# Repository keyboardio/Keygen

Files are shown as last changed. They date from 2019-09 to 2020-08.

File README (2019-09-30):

Setting up:

* Install perl modules
* Check out git submodule

Perl Dependencies:

JSON::XS
Moose

Non-perl Dependencies:

This tool currently builds KiCad 6.0 projects. That's not strictly necessary. If you need us to back down to 5.1, please say so.

There's a git submodule of 'kicad', which includes the keyboardio kicad footprints. Pull requests over there are welcome.

Usage:

perl layout.pl --usb=c --project=104-key --layout=kle-layouts/104.json 
cd 104-key
kicad 104-key.pro

Notes:

It currently generates schematics and layouts assuming a ATMega32U4. The schematic has sheets for three different ways to wire things up: components-on-pcb, teensy 2.0++, arduino-micro.
I know the pro micro is more popular in Japan and I'm happy to have that added as an option.
It'd just need another schematic sheet in the template project and a footprint for adding it to the pcb.
led support is a boolean option. Right now, LEDs are designed as dumb rgb pixels + an issi controller.
the logic parts of the PCB don't get placed or connected to the switch and led matrix automatically. That's a much harder wiring problem.
Instead, I hand-drew layouts for those and place them off the side of the PCB for you to drag into place and wire up.
I have produced two PCBs based on earlier versions of this tool with some manual rework. They did -work-. But results are not guaranteed.

-Jesse
jesse@keyboard.io

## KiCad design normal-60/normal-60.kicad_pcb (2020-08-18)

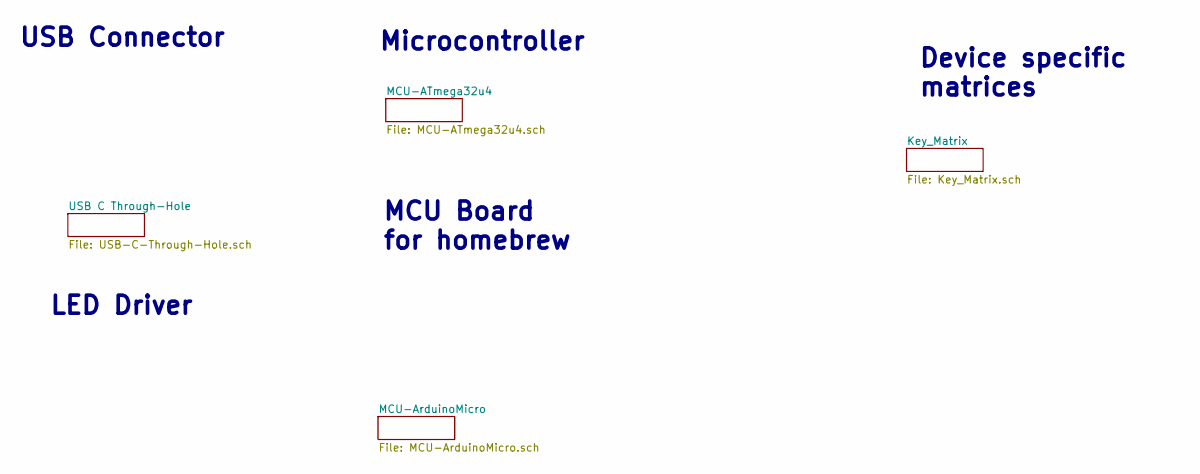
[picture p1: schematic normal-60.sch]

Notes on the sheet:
Device specific matrices
USB Connector
LED Driver
Microcontroller
MCU Board for homebrew

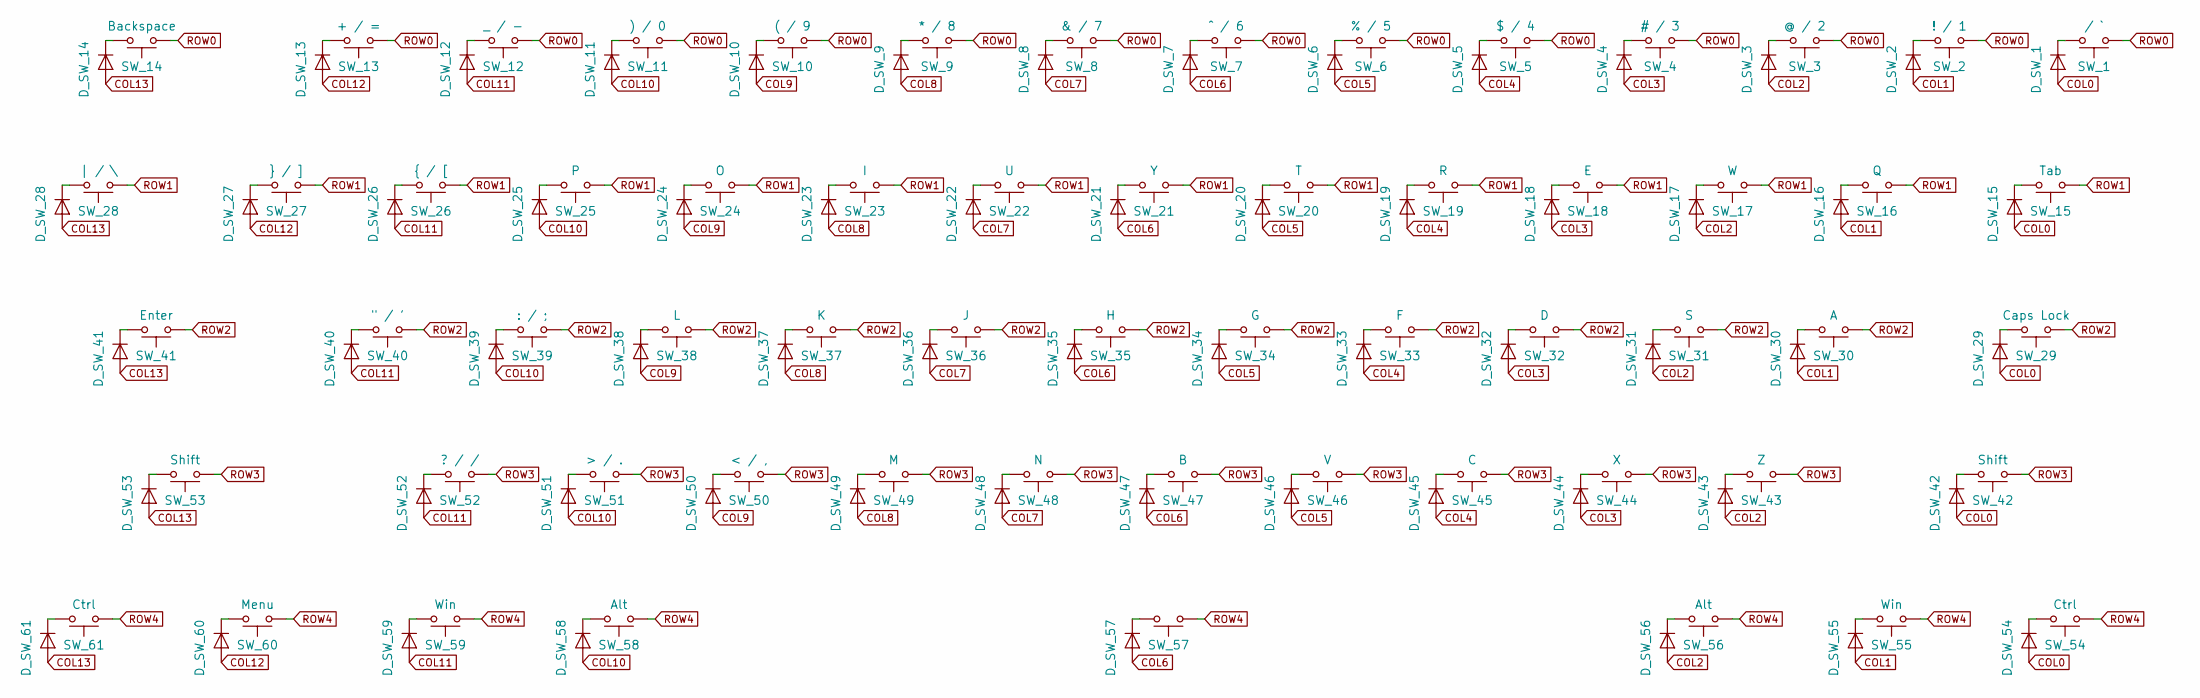
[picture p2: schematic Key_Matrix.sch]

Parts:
D_SW_1, D_SW_2, D_SW_3, D_SW_4, D_SW_5, D_SW_6, D_SW_7, D_SW_8, D_SW_9, D_SW_10, D_SW_11, D_SW_12, D_SW_13, D_SW_14, D_SW_15, D_SW_16, D_SW_17, D_SW_18, D_SW_19, D_SW_20, D_SW_21, D_SW_22, D_SW_23, D_SW_24, D_SW_25, D_SW_26, D_SW_27, D_SW_28, D_SW_29, D_SW_30, D_SW_31, D_SW_32, D_SW_33, D_SW_34, D_SW_35, D_SW_36, D_SW_37, D_SW_38, D_SW_39, D_SW_40, D_SW_41, D_SW_42, D_SW_43, D_SW_44, D_SW_45, D_SW_46, D_SW_47, D_SW_48, D_SW_49, D_SW_50, D_SW_51, D_SW_52, D_SW_53, D_SW_54, D_SW_55, D_SW_56, D_SW_57, D_SW_58, D_SW_59, D_SW_60, D_SW_61: 1N4148; D_SOD-123
SW_1: ~ / `; MX-KailhClip-1.00u
SW_2: ! / 1; MX-KailhClip-1.00u
SW_3: @ / 2; MX-KailhClip-1.00u
SW_4: # / 3; MX-KailhClip-1.00u
SW_5: $ / 4; MX-KailhClip-1.00u
SW_6: % / 5; MX-KailhClip-1.00u
SW_7: ^ / 6; MX-KailhClip-1.00u
SW_8: & / 7; MX-KailhClip-1.00u
SW_9: * / 8; MX-KailhClip-1.00u
SW_10: ( / 9; MX-KailhClip-1.00u
SW_11: ) / 0; MX-KailhClip-1.00u
SW_12: _ / -; MX-KailhClip-1.00u
SW_13: + / =; MX-KailhClip-1.00u
SW_14: Backspace; MX-KailhClip-1.00u
SW_15: Tab; MX-KailhClip-1.00u
SW_16: Q; MX-KailhClip-1.00u
SW_17: W; MX-KailhClip-1.00u
SW_18: E; MX-KailhClip-1.00u
SW_19: R; MX-KailhClip-1.00u
SW_20: T; MX-KailhClip-1.00u
SW_21: Y; MX-KailhClip-1.00u
SW_22: U; MX-KailhClip-1.00u
SW_23: I; MX-KailhClip-1.00u
SW_24: O; MX-KailhClip-1.00u
SW_25: P; MX-KailhClip-1.00u
SW_26: { / [; MX-KailhClip-1.00u
SW_27: } / ]; MX-KailhClip-1.00u
SW_28: | / \\; MX-KailhClip-1.00u
SW_29: Caps Lock; MX-KailhClip-1.00u
SW_30: A; MX-KailhClip-1.00u
SW_31: S; MX-KailhClip-1.00u
SW_32: D; MX-KailhClip-1.00u
SW_33: F; MX-KailhClip-1.00u
SW_34: G; MX-KailhClip-1.00u
SW_35: H; MX-KailhClip-1.00u
SW_36: J; MX-KailhClip-1.00u
SW_37: K; MX-KailhClip-1.00u
SW_38: L; MX-KailhClip-1.00u
SW_39: : / ;; MX-KailhClip-1.00u
SW_40: \" / '; MX-KailhClip-1.00u
SW_41: Enter; MX-KailhClip-1.00u
SW_42, SW_53: Shift; MX-KailhClip-1.00u
SW_43: Z; MX-KailhClip-1.00u
SW_44: X; MX-KailhClip-1.00u
SW_45: C; MX-KailhClip-1.00u
SW_46: V; MX-KailhClip-1.00u
SW_47: B; MX-KailhClip-1.00u
SW_48: N; MX-KailhClip-1.00u
SW_49: M; MX-KailhClip-1.00u
SW_50: < / ,; MX-KailhClip-1.00u
SW_51: > / .; MX-KailhClip-1.00u
SW_52: ? / /; MX-KailhClip-1.00u
SW_54, SW_61: Ctrl; MX-KailhClip-1.00u
SW_55, SW_59: Win; MX-KailhClip-1.00u
SW_56, SW_58: Alt; MX-KailhClip-1.00u
SW_57: MX-KailhClip-1.00u
SW_60: Menu; MX-KailhClip-1.00u

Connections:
COL0: D_SW_1.2 (A), D_SW_15.2 (A), D_SW_29.2 (A), D_SW_42.2 (A), D_SW_54.2 (A); also elsewhere on the board
COL1: D_SW_2.2 (A), D_SW_16.2 (A), D_SW_30.2 (A), D_SW_55.2 (A); also elsewhere on the board
COL2: D_SW_3.2 (A), D_SW_17.2 (A), D_SW_31.2 (A), D_SW_43.2 (A), D_SW_56.2 (A); also elsewhere on the board
COL3: D_SW_4.2 (A), D_SW_18.2 (A), D_SW_32.2 (A), D_SW_44.2 (A); also elsewhere on the board
COL4: D_SW_5.2 (A), D_SW_19.2 (A), D_SW_33.2 (A), D_SW_45.2 (A); also elsewhere on the board
COL5: D_SW_6.2 (A), D_SW_20.2 (A), D_SW_34.2 (A), D_SW_46.2 (A); also elsewhere on the board
COL6: D_SW_7.2 (A), D_SW_21.2 (A), D_SW_35.2 (A), D_SW_47.2 (A), D_SW_57.2 (A); also elsewhere on the board
COL7: D_SW_8.2 (A), D_SW_22.2 (A), D_SW_36.2 (A), D_SW_48.2 (A); also elsewhere on the board
COL8: D_SW_9.2 (A), D_SW_23.2 (A), D_SW_37.2 (A), D_SW_49.2 (A); also elsewhere on the board
COL9: D_SW_10.2 (A), D_SW_24.2 (A), D_SW_38.2 (A), D_SW_50.2 (A); also elsewhere on the board
COL10: D_SW_11.2 (A), D_SW_25.2 (A), D_SW_39.2 (A), D_SW_51.2 (A), D_SW_58.2 (A); also elsewhere on the board
COL11: D_SW_12.2 (A), D_SW_26.2 (A), D_SW_40.2 (A), D_SW_52.2 (A), D_SW_59.2 (A); also elsewhere on the board
COL12: D_SW_13.2 (A), D_SW_27.2 (A), D_SW_60.2 (A); also elsewhere on the board
COL13: D_SW_14.2 (A), D_SW_28.2 (A), D_SW_41.2 (A), D_SW_53.2 (A), D_SW_61.2 (A); also elsewhere on the board
unnamed: D_SW_1.1 (K), SW_1.2
unnamed: D_SW_2.1 (K), SW_2.2
unnamed: D_SW_3.1 (K), SW_3.2
unnamed: D_SW_4.1 (K), SW_4.2
unnamed: D_SW_5.1 (K), SW_5.2
unnamed: D_SW_6.1 (K), SW_6.2
unnamed: D_SW_7.1 (K), SW_7.2
unnamed: D_SW_8.1 (K), SW_8.2
unnamed: D_SW_9.1 (K), SW_9.2
unnamed: D_SW_10.1 (K), SW_10.2
unnamed: D_SW_11.1 (K), SW_11.2
unnamed: D_SW_12.1 (K), SW_12.2
unnamed: D_SW_13.1 (K), SW_13.2
unnamed: D_SW_14.1 (K), SW_14.2
unnamed: D_SW_15.1 (K), SW_15.2
unnamed: D_SW_16.1 (K), SW_16.2
unnamed: D_SW_17.1 (K), SW_17.2
unnamed: D_SW_18.1 (K), SW_18.2
unnamed: D_SW_19.1 (K), SW_19.2
unnamed: D_SW_20.1 (K), SW_20.2
unnamed: D_SW_21.1 (K), SW_21.2
unnamed: D_SW_22.1 (K), SW_22.2
unnamed: D_SW_23.1 (K), SW_23.2
unnamed: D_SW_24.1 (K), SW_24.2
unnamed: D_SW_25.1 (K), SW_25.2
unnamed: D_SW_26.1 (K), SW_26.2
unnamed: D_SW_27.1 (K), SW_27.2
unnamed: D_SW_28.1 (K), SW_28.2
unnamed: D_SW_29.1 (K), SW_29.2
unnamed: D_SW_30.1 (K), SW_30.2
unnamed: D_SW_31.1 (K), SW_31.2
unnamed: D_SW_32.1 (K), SW_32.2
unnamed: D_SW_33.1 (K), SW_33.2
unnamed: D_SW_34.1 (K), SW_34.2
unnamed: D_SW_35.1 (K), SW_35.2
unnamed: D_SW_36.1 (K), SW_36.2
unnamed: D_SW_37.1 (K), SW_37.2
unnamed: D_SW_38.1 (K), SW_38.2
unnamed: D_SW_39.1 (K), SW_39.2
unnamed: D_SW_40.1 (K), SW_40.2
unnamed: D_SW_41.1 (K), SW_41.2
unnamed: D_SW_42.1 (K), SW_42.2
unnamed: D_SW_43.1 (K), SW_43.2
unnamed: D_SW_44.1 (K), SW_44.2
unnamed: D_SW_45.1 (K), SW_45.2
unnamed: D_SW_46.1 (K), SW_46.2
unnamed: D_SW_47.1 (K), SW_47.2
unnamed: D_SW_48.1 (K), SW_48.2
unnamed: D_SW_49.1 (K), SW_49.2
unnamed: D_SW_50.1 (K), SW_50.2
unnamed: D_SW_51.1 (K), SW_51.2
unnamed: D_SW_52.1 (K), SW_52.2
unnamed: D_SW_53.1 (K), SW_53.2
unnamed: D_SW_54.1 (K), SW_54.2
unnamed: D_SW_55.1 (K), SW_55.2
unnamed: D_SW_56.1 (K), SW_56.2
unnamed: D_SW_57.1 (K), SW_57.2
unnamed: D_SW_58.1 (K), SW_58.2
unnamed: D_SW_59.1 (K), SW_59.2
unnamed: D_SW_60.1 (K), SW_60.2
unnamed: D_SW_61.1 (K), SW_61.2
ROW0: SW_1.1, SW_2.1, SW_3.1, SW_4.1, SW_5.1, SW_6.1, SW_7.1, SW_8.1, SW_9.1, SW_10.1, SW_11.1, SW_12.1, SW_13.1, SW_14.1; also elsewhere on the board
ROW1: SW_15.1, SW_16.1, SW_17.1, SW_18.1, SW_19.1, SW_20.1, SW_21.1, SW_22.1, SW_23.1, SW_24.1, SW_25.1, SW_26.1, SW_27.1, SW_28.1; also elsewhere on the board
ROW2: SW_29.1, SW_30.1, SW_31.1, SW_32.1, SW_33.1, SW_34.1, SW_35.1, SW_36.1, SW_37.1, SW_38.1, SW_39.1, SW_40.1, SW_41.1; also elsewhere on the board
ROW3: SW_42.1, SW_43.1, SW_44.1, SW_45.1, SW_46.1, SW_47.1, SW_48.1, SW_49.1, SW_50.1, SW_51.1, SW_52.1, SW_53.1; also elsewhere on the board
ROW4: SW_54.1, SW_55.1, SW_56.1, SW_57.1, SW_58.1, SW_59.1, SW_60.1, SW_61.1; also elsewhere on the board

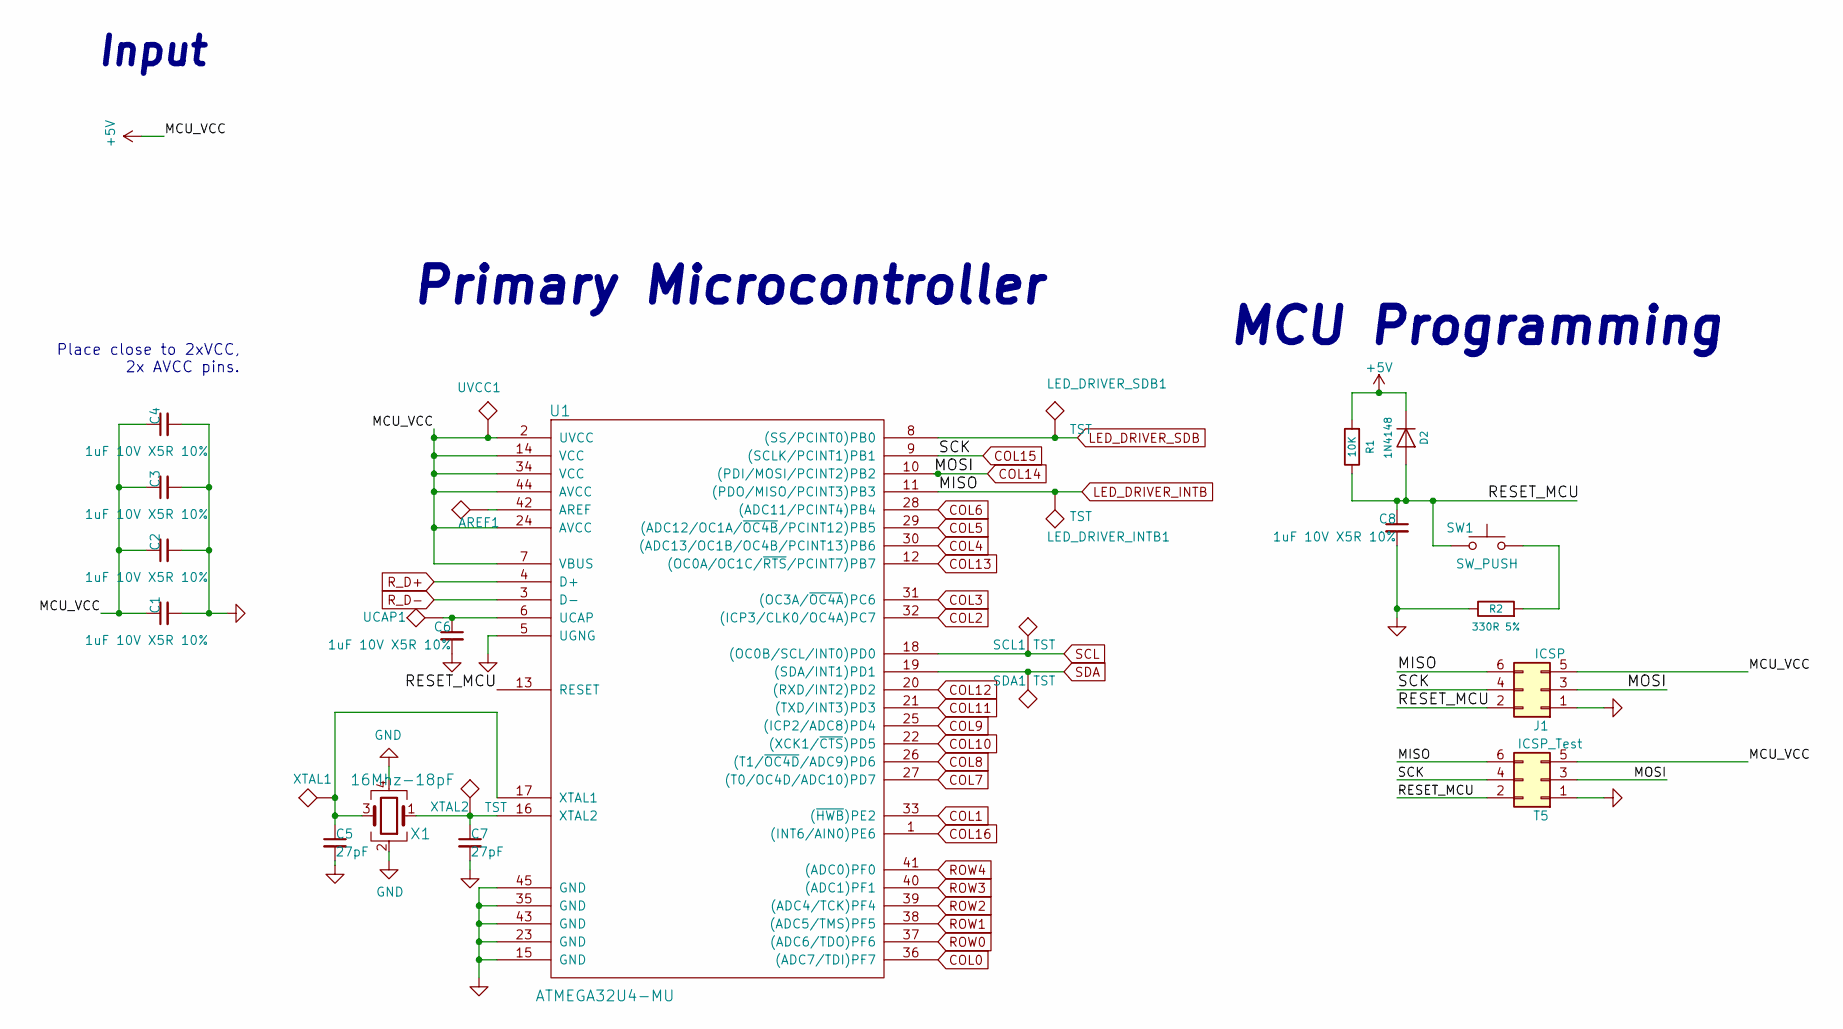
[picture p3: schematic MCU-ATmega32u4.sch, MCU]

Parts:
AREF1: TST; TestPoint_Pad_D1.5mm
C1, C2, C3, C4, C6, C8: 1uF 10V X5R 10%; C_0603_1608Metric; MPN CC0603KRX5R6BB105; DigiKey 311-1443-2-ND
C5, C7: 27pF; C_0603_1608Metric; MPN CC0603JRNPO9BN270; DigiKey 311-1063-1-ND
D2: 1N4148; D_SOD-123; MPN 1N4148W-7-F; DigiKey 1N4148W-FDITR-ND
J1: ICSP; Model_01_ICSP_cutout_pins; MPN M20-8760342; DigiKey 952-1922-ND
LED_DRIVER_INTB1: TST; TestPoint_Pad_D1.5mm
LED_DRIVER_SDB1: TST; TestPoint_Pad_D1.5mm
R1: 10K; R_0603_1608Metric; MPN RR0816P-103-D; DigiKey RR08P10.0KDTR-ND
R2: 330R 5%; R_0603_1608Metric; MPN 311-330GRTR-ND; DigiKey 311-330GRTR-ND
SCL1: TST; TestPoint_Pad_D1.5mm
SDA1: TST; TestPoint_Pad_D1.5mm
SW1: SW_PUSH; SW_SPST_TL3342; MPN TL3342F160QG/TR; DigiKey EG2531TR-ND
T5: ICSP_Test; Six_Pin_Test_Point
U1: ATMEGA32U4-MU; QFN-44-1EP_7x7mm_P0.5mm_EP5.15x5.15mm_ThermalVias; MPN ATMEGA32U4-MU; DigiKey ATMEGA32U4-MU-ND
UCAP1: TST; TestPoint_Pad_D1.5mm
UVCC1: TST; TestPoint_Pad_D1.5mm
X1: 16Mhz-18pF; Crystal_SMD_SeikoEpson_TSX3225-4Pin_3.2x2.5mm; MPN X1E000021069600; DigiKey TSX-322516.0000MF20G-C-ND
XTAL1, XTAL2: TST; TestPoint_Pad_D1.5mm

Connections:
+5V: C1.1, C2.1, C3.1, C4.1, D2.1 (K), J1.5, R1.2, T5.5, U1.2 (UVCC), U1.7 (VBUS), U1.14 (VCC), U1.24 (AVCC), U1.34 (VCC), U1.44 (AVCC), UVCC1.1; also elsewhere on the board
/MCU-ATmega32u4/RESET_MCU: C8.1, D2.2 (A), J1.2, R1.1, SW1.2, T5.2, U1.13 (RESET)
COL0: U1.36 ((ADC7/TDI)PF7); also elsewhere on the board
COL1: U1.33 ((~HWB~)PE2); also elsewhere on the board
COL2: U1.32 ((ICP3/CLK0/OC4A)PC7); also elsewhere on the board
COL3: U1.31 ((OC3A/~OC4A~)PC6); also elsewhere on the board
COL4: U1.30 ((ADC13/OC1B/OC4B/PCINT13)PB6); also elsewhere on the board
COL5: U1.29 ((ADC12/OC1A/~OC4B~/PCINT12)PB5); also elsewhere on the board
COL6: U1.28 ((ADC11/PCINT4)PB4); also elsewhere on the board
COL7: U1.27 ((T0/OC4D/ADC10)PD7); also elsewhere on the board
COL8: U1.26 ((T1/~OC4D~/ADC9)PD6); also elsewhere on the board
COL9: U1.25 ((ICP2/ADC8)PD4); also elsewhere on the board
COL10: U1.22 ((XCK1/~CTS~)PD5); also elsewhere on the board
COL11: U1.21 ((TXD/INT3)PD3); also elsewhere on the board
COL12: U1.20 ((RXD/INT2)PD2); also elsewhere on the board
COL13: U1.12 ((OC0A/OC1C/~RTS~/PCINT7)PB7); also elsewhere on the board
COL14: J1.3, T5.3, U1.10 ((PDI/MOSI/PCINT2)PB2)
COL15: J1.4, T5.4, U1.9 ((SCLK/PCINT1)PB1)
COL16: U1.1 ((INT6/AIN0)PE6)
LED_DRIVER_INTB: J1.6, LED_DRIVER_INTB1.1, T5.6, U1.11 ((PDO/MISO/PCINT3)PB3)
LED_DRIVER_SDB: LED_DRIVER_SDB1.1, U1.8 ((SS/PCINT0)PB0)
unnamed: AREF1.1, U1.42 (AREF)
unnamed: C5.1, U1.17 (XTAL1), X1.3, XTAL1.1
unnamed: C6.1, U1.6 (UCAP), UCAP1.1
unnamed: C7.1, U1.16 (XTAL2), X1.1, XTAL2.1
unnamed: R2.2, SW1.1
ROW0: U1.37 ((ADC6/TDO)PF6); also elsewhere on the board
ROW1: U1.38 ((ADC5/TMS)PF5); also elsewhere on the board
ROW2: U1.39 ((ADC4/TCK)PF4); also elsewhere on the board
ROW3: U1.40 ((ADC1)PF1); also elsewhere on the board
ROW4: U1.41 ((ADC0)PF0); also elsewhere on the board
R_D+: U1.4 (D+); also elsewhere on the board
R_D-: U1.3 (D-); also elsewhere on the board
SCL: SCL1.1, U1.18 ((OC0B/SCL/INT0)PD0)
SDA: SDA1.1, U1.19 ((SDA/INT1)PD1)

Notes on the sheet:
MCU Programming
Primary Microcontroller
Place close to 2xVCC, 2x AVCC pins.
Input

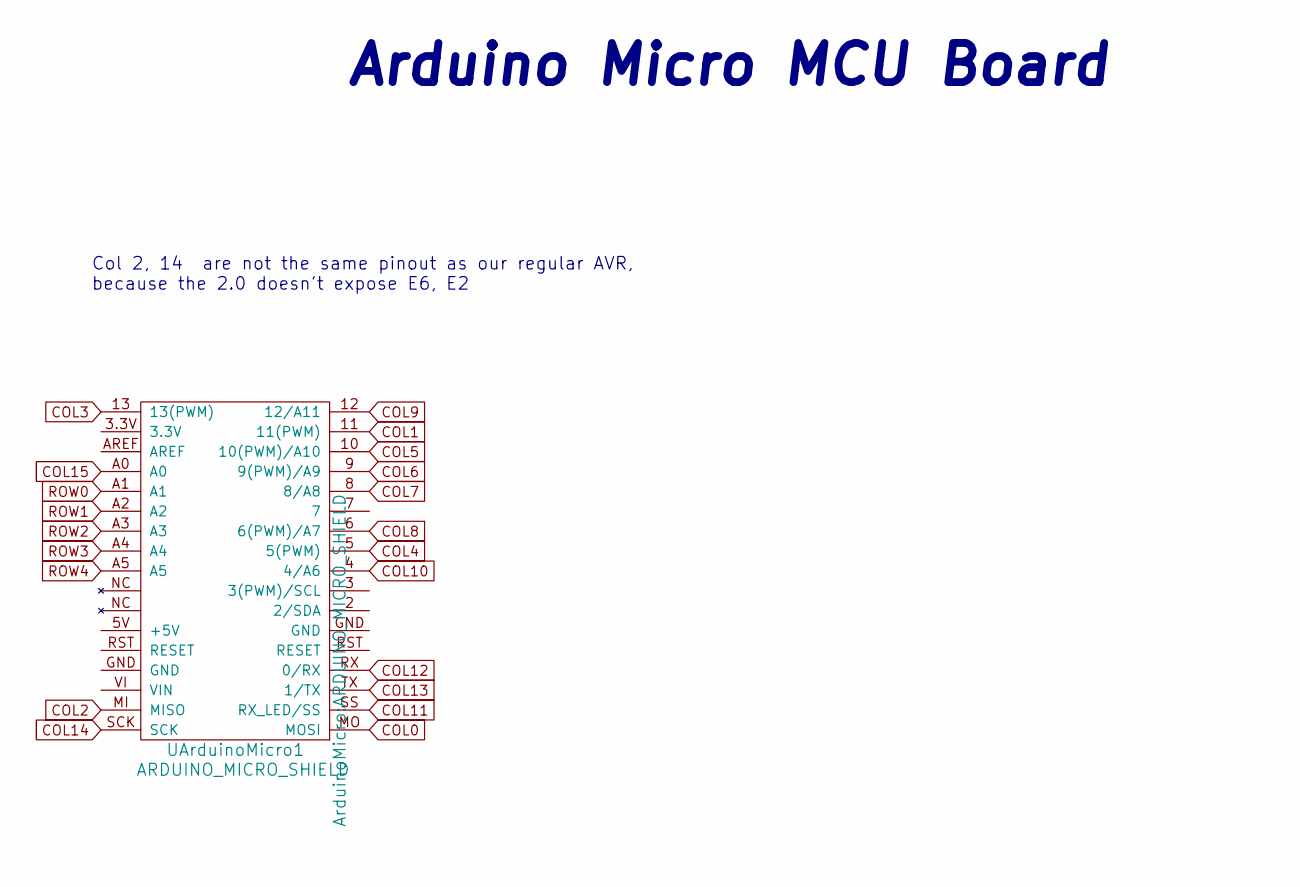
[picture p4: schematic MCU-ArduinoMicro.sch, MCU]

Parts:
UArduinoMicro1: ARDUINO_MICRO_SHIELD

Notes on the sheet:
Arduino Micro MCU Board
Col 2, 14 are not the same pinout as our regular AVR, because the 2.0 doesn't expose E6, E2

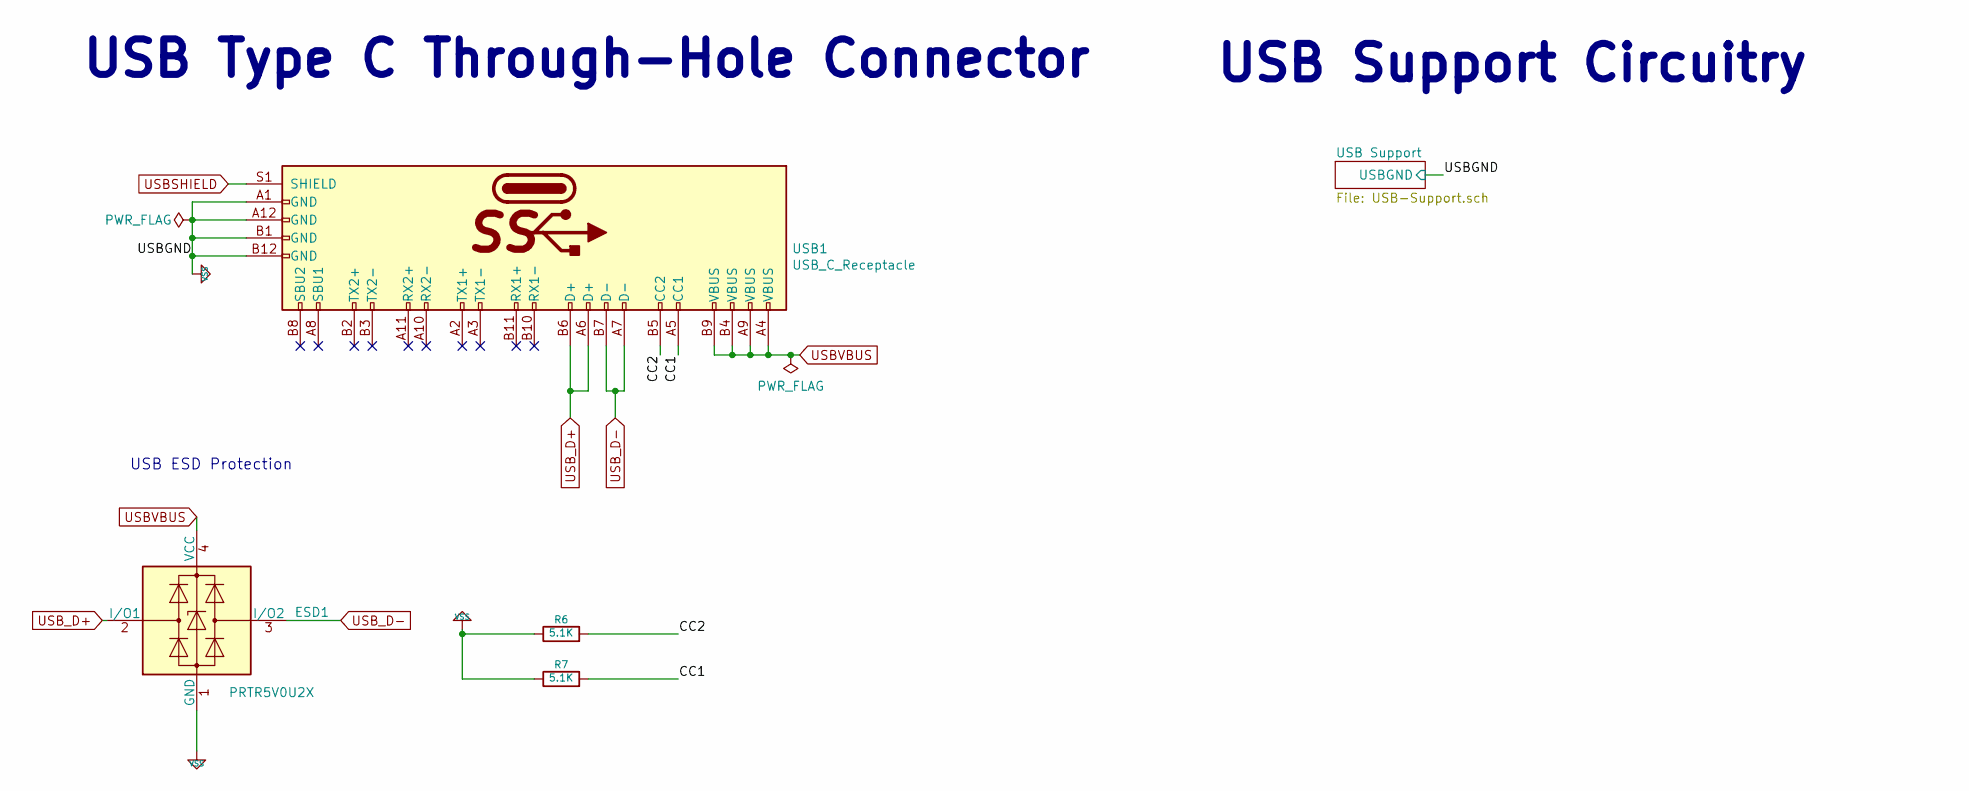
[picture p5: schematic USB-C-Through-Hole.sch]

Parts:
ESD1: PRTR5V0U2X; MPN PRTR5V0U2X; DigiKey 1727-3884-2-ND
R6: 5.1K; R_0603_1608Metric; MPN RT0603BRD075K1L; DigiKey RR08P5.1KDTR-ND
R7: 5.1K; R_0603_1608Metric; MPN RT0603BRD075K1L; LCSC C122969
USB1: USB_C_Receptacle; USB_C_Receptacle_GCT_USB4085; MPN GCT_USB4085

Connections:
/USB C Through-Hole/CC1: R7.2, USB1.A5 (CC1)
/USB C Through-Hole/CC2: R6.2, USB1.B5 (CC2)
USBSHIELD: USB1.S1 (SHIELD); also elsewhere on the board
USBVBUS: ESD1.4 (VCC), USB1.A4 (VBUS), USB1.A9 (VBUS), USB1.B4 (VBUS), USB1.B9 (VBUS); also elsewhere on the board
USB_D+: ESD1.2 (I/O1), USB1.A6 (D+), USB1.B6 (D+); also elsewhere on the board
USB_D-: ESD1.3 (I/O2), USB1.A7 (D-), USB1.B7 (D-); also elsewhere on the board

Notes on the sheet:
USB Type C Through-Hole Connector
USB Support Circuitry
USB ESD Protection

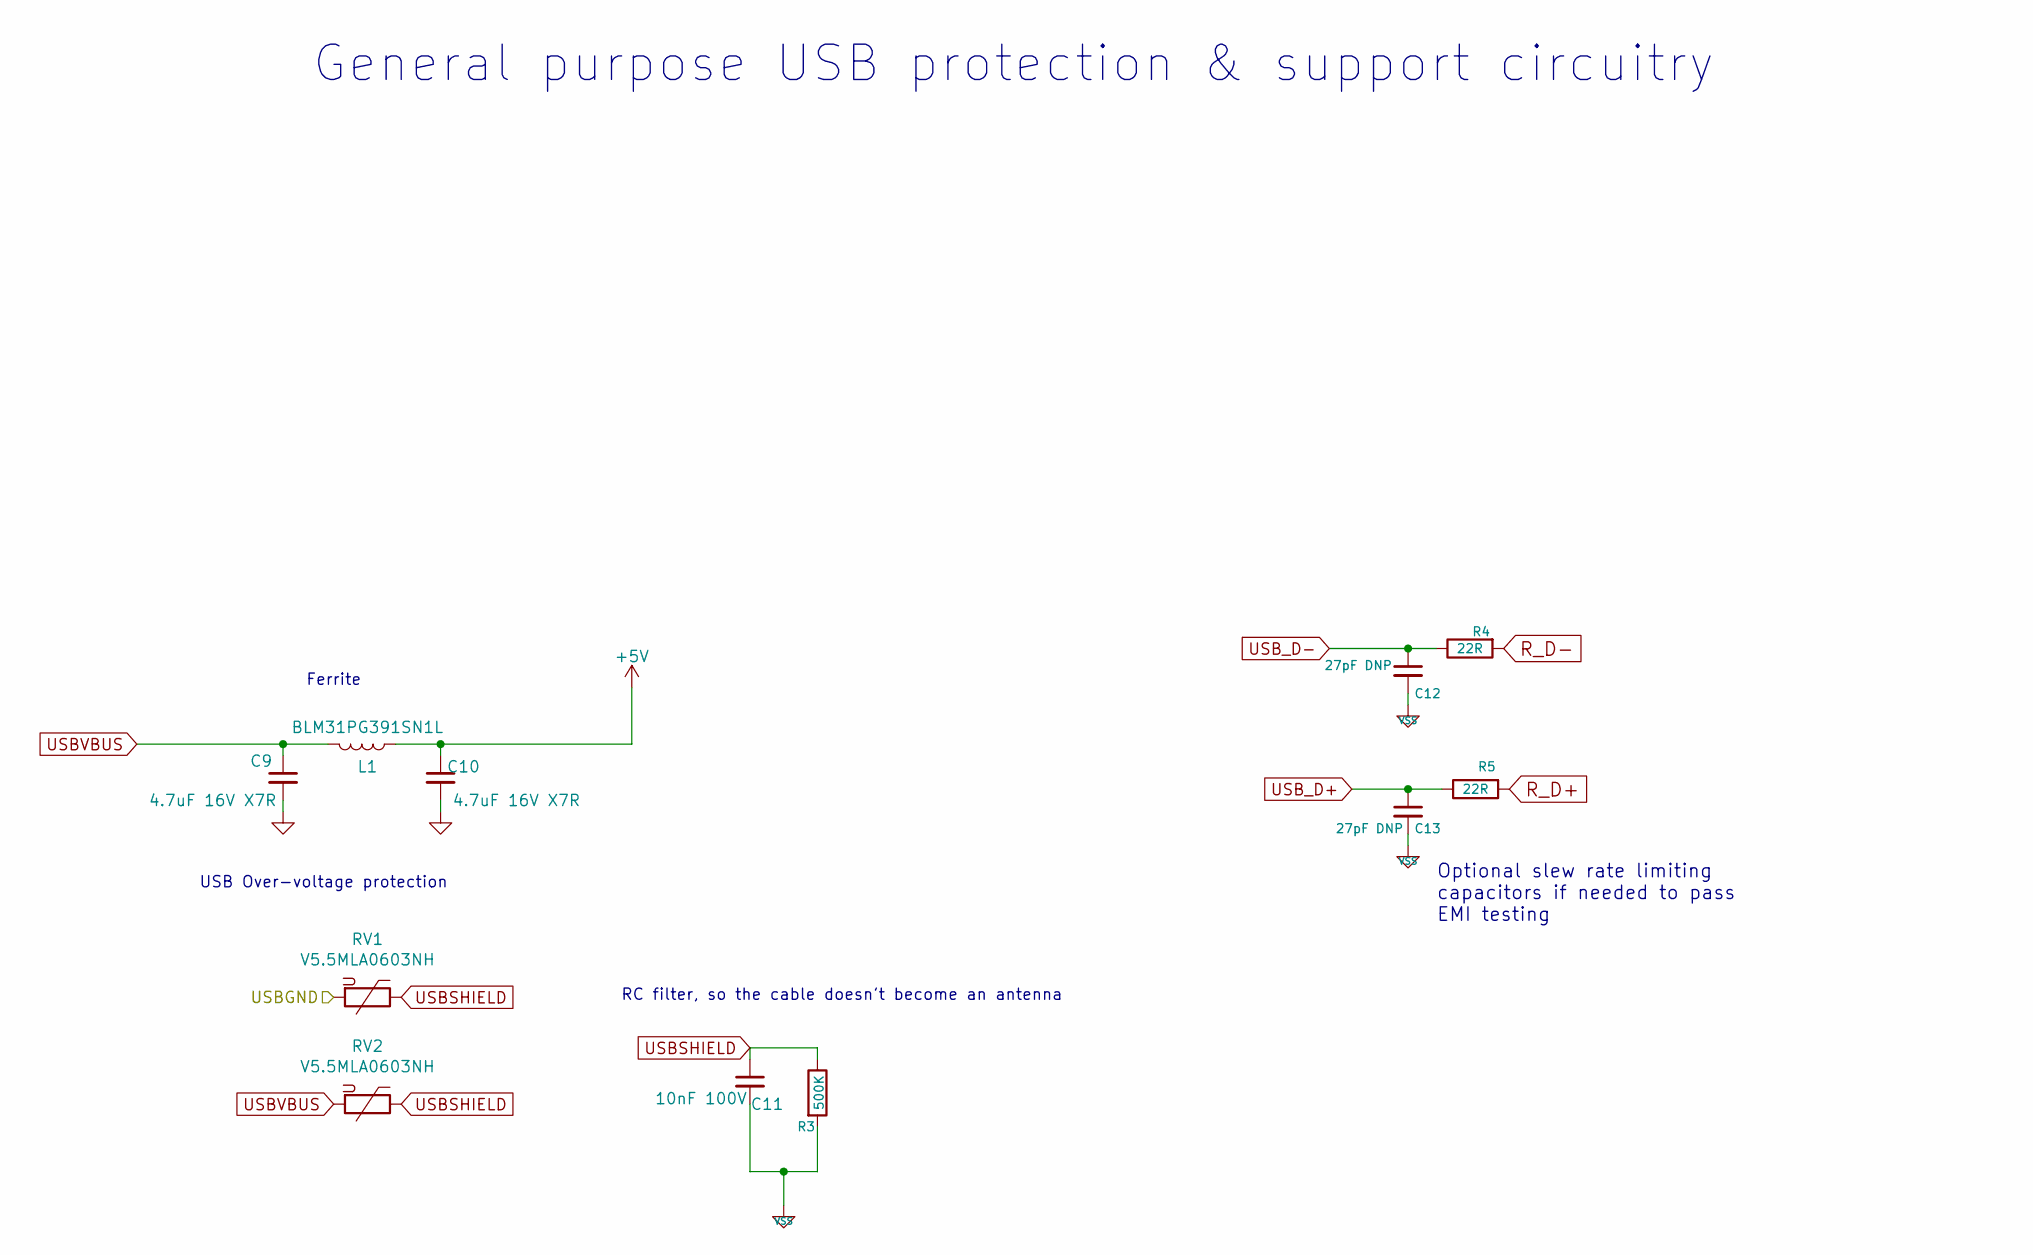
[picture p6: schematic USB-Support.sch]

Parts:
C9, C10: 4.7uF 16V X7R; C_0805_2012Metric; MPN CC0805KKX7R7BB475; DigiKey 311-1883-2-ND
C11: 10nF 100V; C_0805_2012Metric; MPN CC0805KRX7R0BB103; DigiKey 311-1475-1-ND
C12, C13: 27pF DNP; C_0603_1608Metric; MPN CC0603JRNPO9BN270; DigiKey 311-1063-1-ND
L1: BLM31PG391SN1L; R_1206_3216Metric; MPN BLM31PG391SN1L; DigiKey 490-5229-2-ND
R3: 500K; R_0603_1608Metric; MPN RC0603FR-07499KL; DigiKey 311-499KHRTR-ND
R4, R5: 22R; R_0603_1608Metric; MPN RC0603FR-0722RL; DigiKey 311-22.0HRTR-ND
RV1, RV2: V5.5MLA0603NH; R_0603_1608Metric; MPN V5.5MLA0603NH; DigiKey F3363CT-ND

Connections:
+5V: C10.1, L1.1; also elsewhere on the board
R_D+: R5.2; also elsewhere on the board
R_D-: R4.2; also elsewhere on the board
USBSHIELD: C11.1, R3.1, RV1.1, RV2.1; also elsewhere on the board
USBVBUS: C9.1, L1.2, RV2.2; also elsewhere on the board
USB_D+: C13.1, R5.1; also elsewhere on the board
USB_D-: C12.1, R4.1; also elsewhere on the board

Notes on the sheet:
Optional slew rate limiting capacitors if needed to pass EMI testing
Ferrite
USB Over-voltage protection
RC filter, so the cable doesn't become an antenna
General purpose USB protection & support circuitry

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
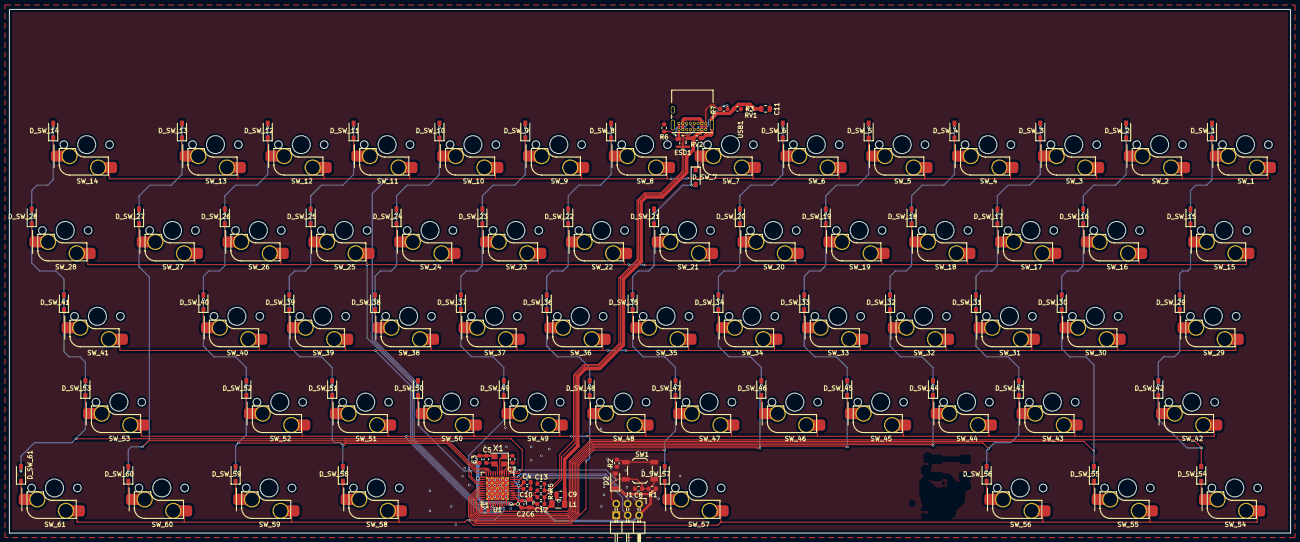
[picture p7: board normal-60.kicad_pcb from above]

Board: 2 copper layers, 284.3 x 116.2 mm, 152 parts (0 on the bottom side), 98 nets.

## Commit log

2019-09-29 check in a version of the keyboard generator without keyboardio's secret projects
    [Key_Matrix.sch, LED_Driver-ISSI.sch, LED_Matrix.sch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]
2019-10-02 Add a new USB C variant: the GCT USB4085, which is entirely through-hole
2019-10-02 Starting to add schematic support for the through-hole USB C connector
    [USB-C-Through-Hole.sch]
2019-10-02 update to add USB C through-hole connector
    [Key_Matrix.sch, LED_Driver-ISSI.sch, LED_Matrix.sch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]
2019-10-02 conditionally include our arduino micro socket
2019-10-02 fix a bug in our schematic item removal
2019-10-05 doc c-through-hole
2019-10-06 working on adding support for jlcpcb small batch assembly
    [LED_Driver-ISSI.sch, MCU-ATmega32u4.sch, USB-C-Through-Hole.sch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]
2019-10-06 It appears that kicad tried to renumber some of our parts
    [USB-Support.sch]
2019-10-06 undo some of the dumb autonumbering
    [USB-C-Through-Hole.sch, USB-C.sch]
2019-10-10 Trying to get back to Kicad 5.1 compat and fix USB routing
    [Key_Matrix.sch, LED_Driver-ISSI.sch, LED_Matrix.sch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]
2019-10-12 added a couple more sample layouts
2019-10-13 Added an example of a 60% routed with this tooling
    [Key_Matrix.sch, MCU-ATmega32u4.sch, MCU-ArduinoMicro.sch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]
2019-10-14 make it work with 5.1 again
    [kicad-template.kicad_pcb]
2020-08-18 snapshot changes
    [MCU-ATmega32u4.sch, normal-60.kicad_pcb]

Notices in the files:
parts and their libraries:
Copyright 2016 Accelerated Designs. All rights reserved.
